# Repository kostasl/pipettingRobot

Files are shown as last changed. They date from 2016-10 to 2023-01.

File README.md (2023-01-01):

## Liquidhandler Robot 
@author: Konstantinos Lagogiannis 

This project provides part of the resources required to make an automated pipetting machine (robot)
that can be used in biology labs or just for fun.

The project describes the hardware  and assembly requirements  
along with the electronic and code components to build a gantry robot on which a 
standard pipeteman can be mounted. 
check out:https://hackaday.io/project/161546-pippeting-robot

The original idea is based on opentrons, ot.one however this design is heavily modified and simplified on the the controller side as it  does not require a connected PC to run. This also means it does not provide the all the functionality and flexibility of the OT.ONE software platform. It can be used as a simple platform to run repetitive procedures that can be coded on the controller or saved on a SD card. 

However, at this stage only the controller code is publicably available on this repository.
The code is part of an opensource project I wish to make on an affordable lab pipetting robot that can mount a standard lab pipette. 

A video of the prototype can be found here : https://www.youtube.com/watch?v=jlGT0nzT_E8

The provided version of the code operates the prototype  and can provide the basis for future development. However, I have yet to provide sufficient documantation for thise project , and thus thus this holds back release to the public domain as a complete open project which I can share.

*************************************

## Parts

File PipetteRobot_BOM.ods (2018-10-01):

Pipette Robot BOM
Category | Part Number | Part Name | Quantity | Description | Supplier | Price
Lasercut
 | 1001 | Baseplate | 1 | 6061 Aluminum, Anodized, 3mm
 | 1002 | Motor Mount Plate | 5 | Acrylic, 3mm
 | 1003 | Computer Mount Set | 1 set | Acrylic, 3mm
 | 1004 | Home Switch Mount Set | 1 set | Acrylic, 3mm
 | 1005 | Z Rail Spacer | 1 | Acrylic, 5mm
 | 1006 | Pipette Rail Mount | 1 | Acrylic, 5mm
 | 1007 | A Motor Mount Set | 1 set | Acrylic, 8mm
 | 1008 | Z Motor Mount | 1 | Acrylic, 8mm
 | 1009 | Z Motor Lock | 1 | Acrylic, 8mm
 | 1010 | Cable Rail Bracket | 2 | Acrylic, 8mm
 | 1011 | Baseplate Rails | 1 set | Acrylic, 3mm, 8mm
 |  | 8mm Acrylic Sheet
 |  | 5mm Acrylic Sheet
 |  | 3mm Acrylic Sheet
3D Print
 | 1100 | Belt Clip | 3 sets | PLA
 | 1101 | Pipette Holder | 1 | PLA
 | 1102 | Pipette Stopper | 1 | PLA
 | 1106 | Z Motor Mount | 1 | PLA
 | 1107 | Z Motor Lock | 1 | PLA
 | 1150 | Tip Clip | 1 | PLA
 | 1151 | Z Switch Block | 1 | PLA
 | 1152 | Pipette Rail Mount | 1 | PLA
Motors and Wheels
 | 1200 | Nema 17 Stepper Motor | 3 | Motor used for Y1, Y2, and X rails | Zapp | 42.78
 | 1201 | Nema 17 Stepper Motor - JK42HS40-1004YAL | 1 | Motor used for Z Axis, 300mm Captive Lead screw | Banggood | 20.44 | Zapp | 59.4
 | 1202 | Nema 17 Stepper Motor | 2 | Motor used for A pipette, 100mm Captive Lead screw | Zapp | 118.8
 | 1203 | Pulley | 3 | MX5-20 pulley for Y1, Y2, and X motors | Amazon | 7
 | 1204 | Wheels | 16 | Delrin V-Profile Wheel Kit | http://ooznest.co.uk/Solid-V-Wheel | 63.05
 | 1205 | Belt | 3 | MX5-belt – 600mm | Amazon | 0
 |  |  | 1 |  | http://robotseed.com/index.php?id_product=13&controller=product&id_lang=2 | 135.6
Electrical / Electronic
 | 1300 | Homeswitch | 4 | Micro switch used for homing feedback
 | 1301 | Homeswitch Cable | 2 | 3 pin, 2m long for Z and A home switch
 | 1302 | Homeswitch Cable | 2 | 3 pin, 1 m long for X and Y home switch
 | 1303 | Motor Cable | 4 | 4 pin, 2m long for Y, X, Z, and A motors
 | 1304 | Y-Split Cable | 1 | 4pin splits into two sections for Y1, and Y2 motor. 41Cm long
 | 1305 | Power Supply | 1 | 12V, 5.0A
 | 1306 | Power Button | 1
 | 1307 | Power Supply Cord | 1
 | 1308 | Drag Chain Cable Carrier 10 x 20mm | 2 |  | amazon sourcing map | 17.28
 | 1309 | Aluminum Board Case | 1 | 145mm x 85mm x 200mm
 |  | Arduino Duo Controller | 1 set | Runs Motor Loop/Reads Data from SD Card (To Be specified)
 |  | OLED Screen for Joystick | 1 set | Screen (To Be specified)
 |  | SD Card Reader | 1 set | (To Be specified)
 |  | Analog joystick | 1 | (To Be specified)
 |  | push buttons | 4 | (To Be specified)
Nuts and Bolts
 | 1400 | M8 Flathead Socket Cap Screw | 10 | 14mm
 | 1401 | M5 Buttonhead Socket Cap Screw | 4 | 35mm | 92
 | 1402 | M5 Buttonhead Socket Cap Screw | 19 | 14mm
 | 1403 | M5 Buttonhead Socket Cap Screw | 14 | 12mm
 | 1404 | M5 Buttonhead Socket Cap Screw | 40 | 10mm
 | 1405 | M5 Buttonhead Socket Cap Screw | 15 | 8mm
 | 1406 | M4 Flathead Socket Cap Screw | 2 | 8mm
 | 1407 | M4 Buttonhead Socket Cap Screw | 6 | 10mm
 | 1408 | M4 Buttonhead Socket Cap Screw | 1 | 10mm
 | 1409 | M3 Sockethead Cap Screw | 5 | 12mm
 | 1410 | M3 Buttonhead Socket Cap Screw | 8 | 16mm
 | 1411 | M3 Buttonhead Socket Cap Screw | 24 | 12mm
 | 1412 | M3 Buttonhead Socket Cap Screw | 30 | 8mm
 | 1413 | M5 T-Slide Nut | 34 | 15mm x 15mm x 6mm
 | 1414 | M5 T-Slide Nut | 33 | 10mm x 10mm x 5mm
 | 1415 | M5 Locknut | 6
 | 1416 | M5 Elastic Nut Ball Nut | 4 | 13.5mm x 8.5mm x 4.5mm
 | 1417 | M4 Square Nut | 8
 | 1418 | M4 T-Slide Nut | 4 | 15mm x 15mm x 6mm
 | 1419 | M3 T-Slide Nut | 2 | 10mm x 10mm x 5mm
 | 1420 | M3 washer | 8
 | 1421 | M3 nut | 24
 | 1422 | M3 insert | 16 | 5mm height, press fit
 | 1423 | M5 Standoff | 1 | 30mm length, Both sides female
 | 1424 | M3 Standoff | 12 | 45mm length, 1 side male 1 side female
 | 1425 | M3 Standoff | 4 | 60mm length, 1 side male 1 side female
 | 1426 | M3 Standoff | 4 | 6mm, 1 side male 1 side female
 | 1427 | L Bracket | 27 | 30mm x 30mm x 20mm
 | 1428 | L Bracket | 2 | 20mm x 20mm x 20mm
 | 1429 | 3-Side Bracket | 4 | 30mm x 30mm x 30mm
 | 1430 | Pin | 4 | 3mm Diameter, 8mm Height
 | 1431 | Precision Rod | 3 | 5mm Diameter, 100mm height | amazon sourcing map | 4.89
 | 1432 | Spacer | 3 | 5mm diameter, 8mm height
 |  | Mini V Precision Shim | 15 | 1mm thick | Ooznest | 4.2
 | 1433 | Phillips Self-Tap Screw | 4 | 16mm
 | 3842519318 | 20x20 Corner Bracket & Fixings (http://www.aluminium-profile.co.uk/cgi-bin/ss001001.cgi?PRODREF=3842519318&NOLOGIN=1) | 4 |  | http://www.aluminium-profile.co.uk/acatalog/Aluminium_Profile_Corner_Brackets.html#SID=15 | 12.6
Rails | 3842517146 | Domed Bracket Cap (http://www.aluminium-profile.co.uk/cgi-bin/ss001001.cgi?PRODREF=3842517146&NOLOGIN=1) | 4 |  | http://www.aluminium-profile.co.uk/acatalog/Aluminium_Profile_Corner_Brackets.html#SID=16 | 4.4
 | KJN523135 | M4 T Nut (10pk) (http://www.aluminium-profile.co.uk/cgi-bin/ss001001.cgi?PRODREF=KJN523135&NOLOGIN=1) | 40 |  | http://www.aluminium-profile.co.uk/acatalog/aluminium_Profile_T_Nuts.html#SID=8 | 12
 | KJN523140 | M4 Slide Block (10pk) | 10 |  | http://www.aluminium-profile.co.uk/acatalog/aluminium_Profile_T_Nuts.html#SID=9 | 10.2
 | KJN523511 | 20x20 L Bracket with Fixings | 32 |  | http://www.aluminium-profile.co.uk/acatalog/20x20-Bracket-with-Fixings-KJN523511.html#SID=26 | 41
 |  | M4x35mm A2 Stainless Steel Hex | 20 |  | amazon DBA | 2.57
 |  | M4x18mm CounterSank Flathead | 100 |  | amazon sourcing map | 7.96
 |  | M4x16mm A2 Stainless Steel Socket Allen Key Dome Head Bolt (https://www.amazon.co.uk/gp/product/B00A7BSOXW) | 100 |  | amazon | 6.6
 |  | M4x12mm ButtonHead Screws (20 Pack) | 20 |  | amazon | 1.45
 |  | M4x8mm Button Head 50pc | 50 |  | amazon | 2.9
 |  | M4 Square Nut A2 Stainless Steel (50 Pack). | 50 |  | amazon | 3.35
 |  | M4 Washer 4.3mm A2 Stainless Steel | 50 |  | amazon | 2.65
 |  | M3x12mm Countersunk Bolts | 20 |  | amazon | 2
 |  | M3x6mm Countersunk Bolts | 20 |  | amazon | 1.05
 |  | 100mm x 5mm HSS Ground Shaft Round Rod | 5 |  | amazon sourcing map | 4.89
 |  | Eccentric Spacer | 14 | Full Size wheel -Size 6mm | oozest | 28.01
 | 1500 | Frame – Base Rails | 4 | Aluminum Extrusion – J3030 – 20mm x 40mm x 500mm -BR Aluminium Profile 6mm slot | http://www.aluminium-profile.co.uk/ | 14
 | 1500 | Frame – Base Rails small | 5 | Aluminum Extrusion – KJN992888 – 20mm x 20mm x 500mm -BR Aluminium Profile 6mm slot | http://www.aluminium-profile.co.uk/ | 12.5
 | 1501 | Frame – Top Rails | 4 | Aluminum Extrusion – KJN992890 – 20mm x 20mm x 500mm BR Aluminium Profile 6mm slot | http://www.aluminium-profile.co.uk/ | 11.52
 | 1502 | Frame – Posts | 4 | Aluminum Extrusion – KJN992890 – 20mm x 20mm x 600mm | http://www.aluminium-profile.co.uk/acatalog/20x20-Aluminium-Profile--KJN992888.html | 13.44
 | 1503 | Frame – Cable Rail Support | 1 | Aluminum Extrusion – KJN992888 – 20mm x 20mm x 490mm |  | 2.46
 | 1504 | Frame – Cable Rail Support | 1 | Aluminum Extrusion – KJN992888 – 20mm x 20mm x 500mm |  | 2.5
 | 1505 | X and Y Linear Rail | 3 | Aluminum Extrusion – V-Profile – 20mm x 40mm x 500mm | http://ooznest.co.uk/ | 18
 | 1506 | Z Linear Rail | 1 | Aluminum Extrusion – V-Profile – 20mm x 40mm x 330mm |  | 7.2
 | 1507 | A Rail - Hold rail of Pippet Rail | 1 | Aluminum Extrusion – KJN992891 – 40mm x 20mm x 175mm |  | 1.55
 | 1508 | Pipette Rail | 1 | Aluminum Extrusion – KJN992888 – 20mm x 20mm x 125mm | http://www.aluminium-profile.co.uk/acatalog/20x40-Aluminium-Profile-KJN992891.html#SID=31 | 1
 |  |  |  |  | Total | 641.84

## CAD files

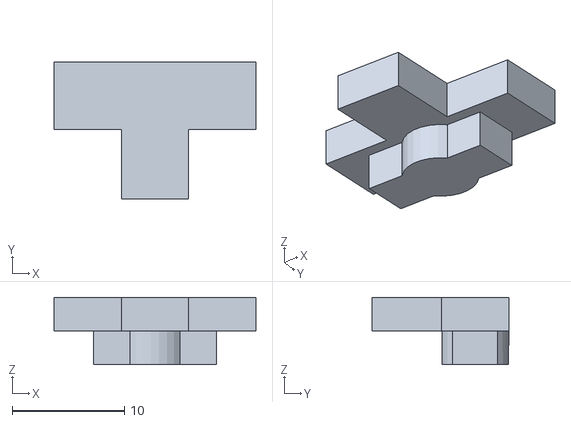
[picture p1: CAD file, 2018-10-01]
ToManufacture/Basis/1001_Guide05x4.stl
18.0 x 12.2 x 6.00

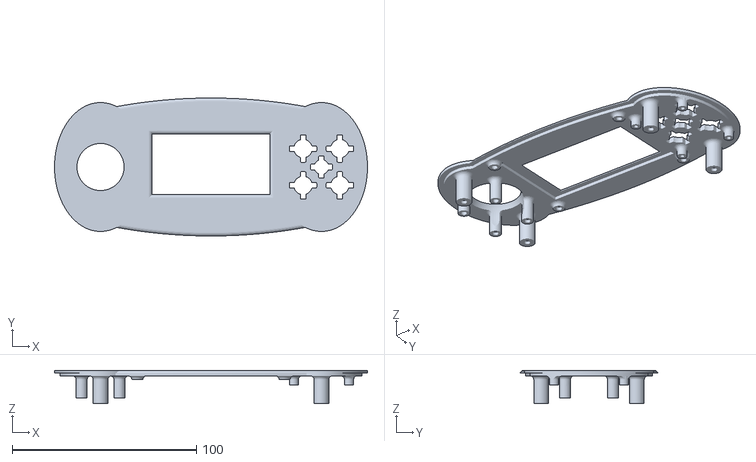
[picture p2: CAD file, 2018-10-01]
ToManufacture/JoystickCase_Front.stl
170.0 x 74.9 x 18.0

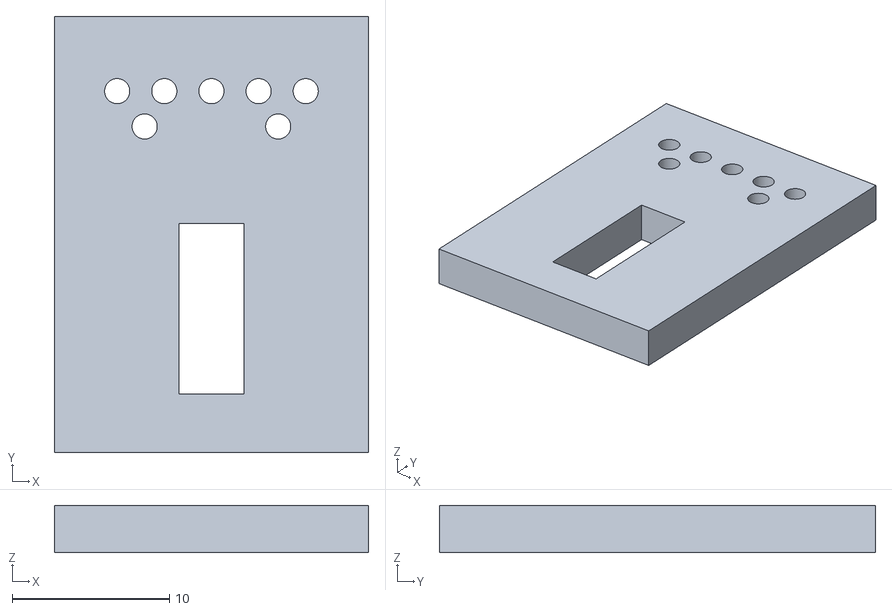
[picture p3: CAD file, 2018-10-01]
ToManufacture/1004_Home_Switch_Mount_Set.stl
20.0 x 27.8 x 3.00

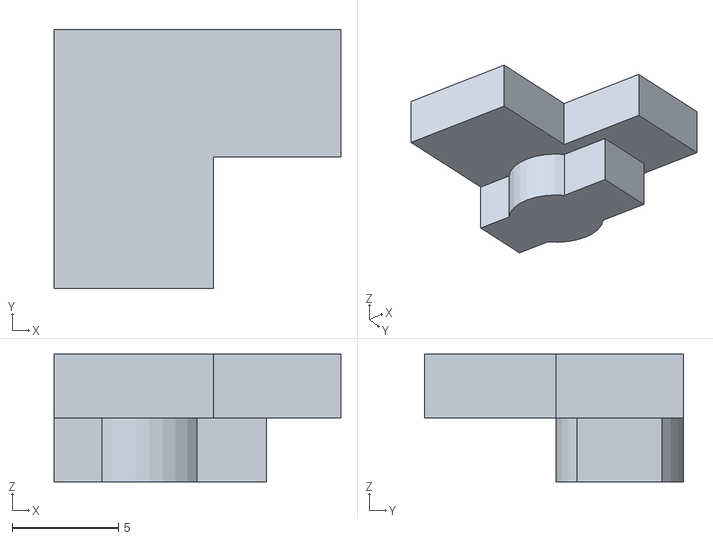
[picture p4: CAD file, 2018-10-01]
ToManufacture/Basis/1001_Guide03x2.stl
13.5 x 12.2 x 6.00

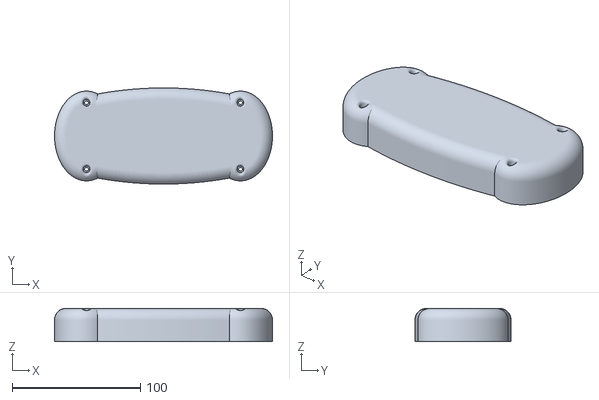
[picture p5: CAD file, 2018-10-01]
ToManufacture/JoystickCase_Back.stl
170.0 x 74.9 x 26.0

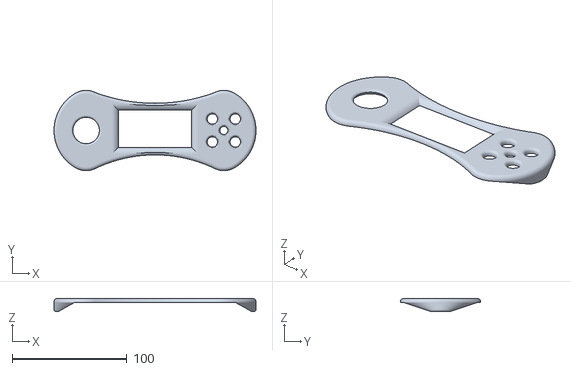
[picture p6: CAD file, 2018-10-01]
ToManufacture/JoystickCase_FrontRubber.stl
176.0 x 70.0 x 11.5

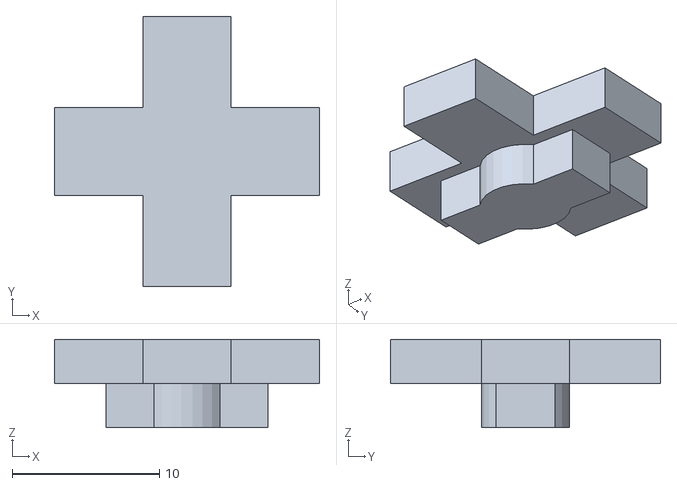
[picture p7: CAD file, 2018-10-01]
ToManufacture/Basis/1001_Guide06x4.stl
18.0 x 18.4 x 6.00

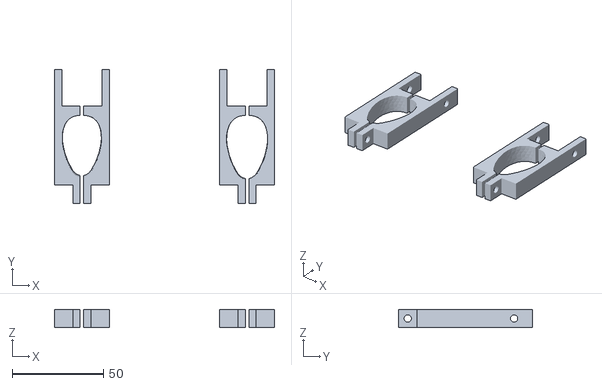
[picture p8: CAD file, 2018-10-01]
ToManufacture/Pipette_MountBoth.stl
120.5 x 73.2 x 10.00

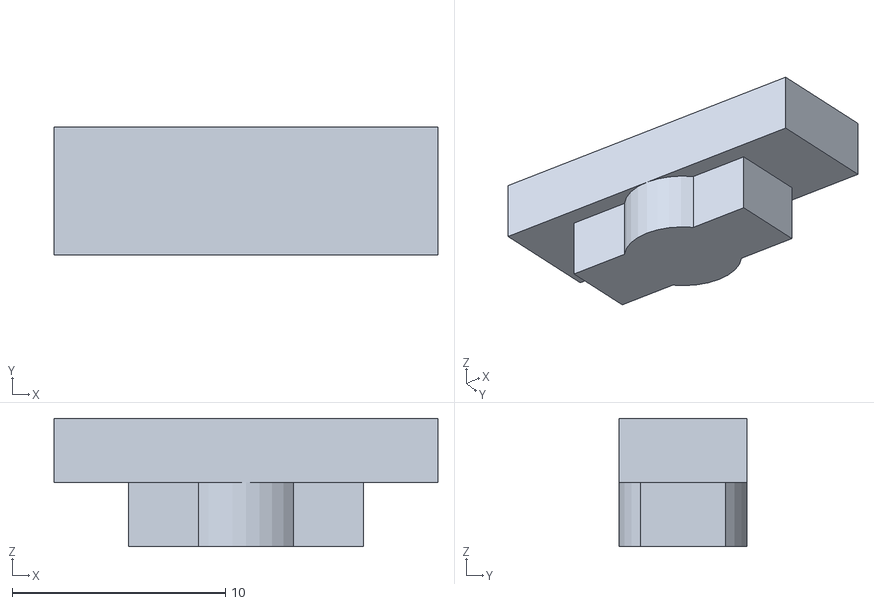
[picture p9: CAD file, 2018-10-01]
ToManufacture/Basis/1001_Guide01x2.stl
18.0 x 6.00 x 6.00

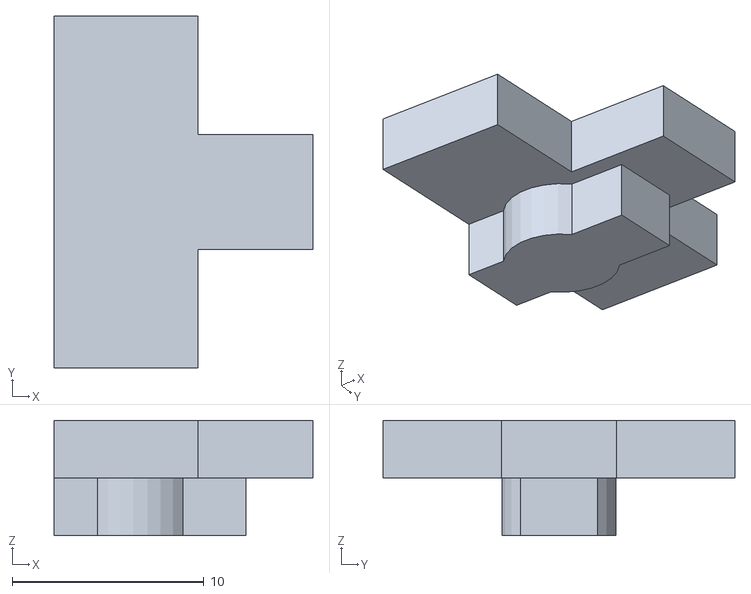
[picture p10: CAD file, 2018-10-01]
ToManufacture/Basis/1001_Guide04x4.stl
13.5 x 18.4 x 6.00

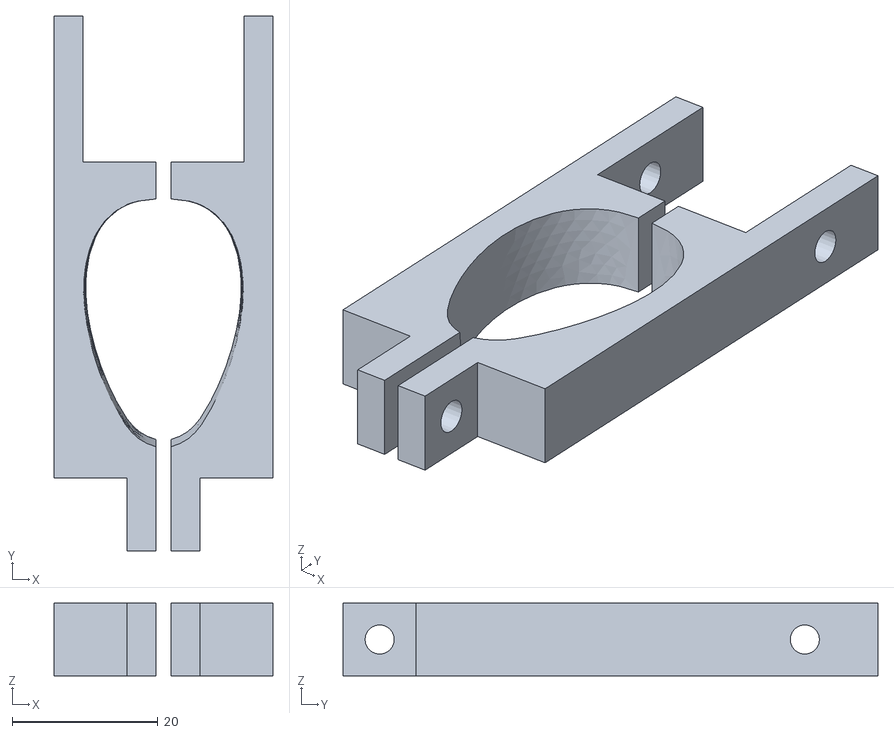
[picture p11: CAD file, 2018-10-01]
ToManufacture/Pipette_Mount1.stl
30.0 x 73.2 x 10.00

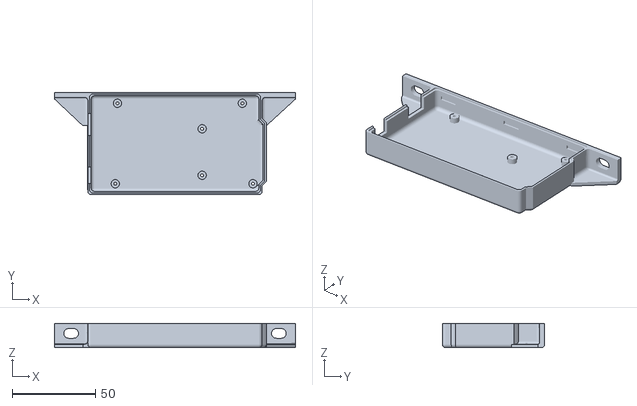
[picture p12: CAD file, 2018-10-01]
ToManufacture/arduino_mega_bottom.stl
144.5 x 61.3 x 14.5

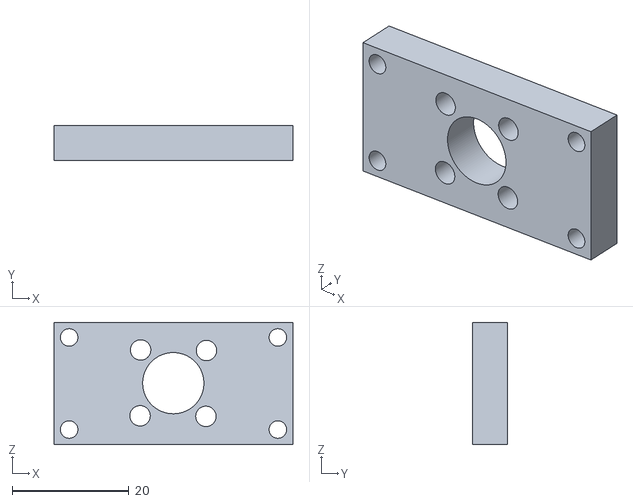
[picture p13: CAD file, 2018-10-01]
ToManufacture/1009_Z_Motor_Lock.stl
41.0 x 6.00 x 21.0

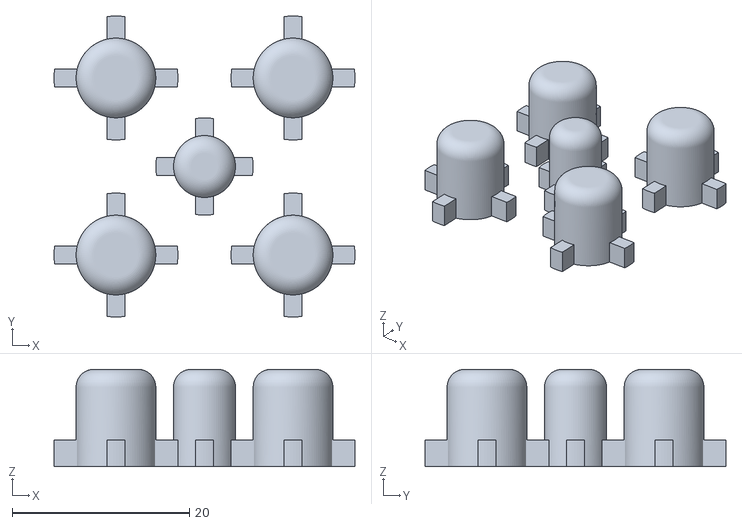
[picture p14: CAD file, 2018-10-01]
ToManufacture/Joystick_Buttons.stl
34.0 x 34.0 x 11.0

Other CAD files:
ToManufacture/Basis/1001_Guide07x2.stl
ToManufacture/Basis/1001_Guide02x2.stl
ToManufacture/1001_A_Baseplate.dwg
ToManufacture/1002_Z_Mount_Plate.stl
ToManufacture/PipettePress.stl
ToManufacture/Pipette_Mount2.stl
ToManufacture/Powersource_Mount.stl

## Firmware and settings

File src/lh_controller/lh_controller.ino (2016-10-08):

/*      Pipeting Robot Controller code -running on Arduino Mega 2560  ///////////////
// 
// Author: Kostas Lagogiannis costaslag@gmail.com 2016
// Synopsis:
    This code is to be used to run on the controller of the associated open hardware design pipetting machine.
    It drives the following peripherals:
    *Step. MotorDriver X,Step MotorDriver Y, Step MotorDriver  Z (Ballscrew), Step MotorDriver P (Non Captive ballscrew) -
    these are controller via 3 wire interface wired to the arduino board at pin number defined in the header file.
    We use a 3 wire interface to each MotorDriver (EN, DIR, STEP - HY-DIV268N-5A with active Low setup on pins)
    
    Using the AccelStepper Library V 1.51 that contains the Multistepper class too (not currently used)
    ///AccelStepper(uint8_t interface =AccelStepper::FULL4WIRE, uint8_t pin1 = 2, uint8_t pin2 = 3, uint8_t pin3 = 4, uint8_t pin4 = 5, bool enable = true);
    \param[in] is the Step input to the driver. Low to high transition means to step)
    \param[in] this is the Direction input the driver. High means forward
    \param[in] enable If this is true (the default), enableOutputs() will be called to enable the output pins at construction time.


    Display: 2.7inch OLED 128x64: Using Adafruit GFX and Adafruit1325 Driver 
    Font structures for newer Adafruit_GFX (1.1 and later).
    Example fonts are included in 'Fonts' directory.
    To use a font in your Arduino sketch, #include the corresponding .h
    file and pass address of GFXfont struct to setFont().  Pass NULL to
    revert to 'classic' fixed-space bitmap font.

    User interface: 5 buttons on right hand           + Joystick with Button On Left Hand
    1 2 1: Up Z Axis , 2: Up Pipette Axis              Button  (When Idle )starts programming mode (Prg Mode) Save position
     3  3: (When Idle Load & execute SD program) (Prog Mode) Stops Program Mode/Replays Saved Program       
    4 5 4: Down Z Axis, 5: Down Pipetter
// Note Any imported library is copied to the local sketchbook subfolder
//// Revision and Notes
// 26/5/16: -Bug : I changed something and the accelleration to Homing Has failed
// 4/6/16 : Changed pin wiring to use Digitalpins header, Moved definitions to dedicated header file  
// 10/6/16 Added Learning pos sequence via joystic - and replay- Note sometimes sequence run stops and needs to issue SST 4 again
// 12/06/12 Added Switch debouncing - Handling of 5 extra controller/joystick buttons for learning pos. 
   Problems To FIX:Jitter/drift on Y axis backwards,Z axis sometimes does not home completely thus zero position misplaced causes crash through tip holder!
  27/06/16 Added Support for SD Card
  03/07/16 There are issues with replay positionioning especially for P, Need to stop it from exceeding upper limit (where there is no switch - limit to steps 3500 / or add physical Sw)
  10/07/16 Made Program Saving/Loading from SD Card, with replay - But problems after 1st replay - loading again fails/readis from random mem
  11/07/16 Fixed bug above, was due to using free instead of delete/new combination for dyn memory alloc/dealloc
  23/07/16 Added Conservative error handling to avoid colission with Limit SW glitch //Was not enough-> Added manual dig pin read of SW in checkHoming to verify what the RDBButton Reads -
            This seems fix the glitch! prob bug in RDBLibrary!
            *Need to add HOMING before any Prog execution  - Also need to make SW clitches captured during replay
            
  02/10/16 Added homing before program loading, remove reset at homing
  04/10/16 Added 2 stage Homing (z 1st, then XYP), added menu scroll for loading and adding new program, changed to JoyButton for select
  05/10/16 Fixed Scrolling, But problem of freezing remains - I removed dynamic memory allocation and created a global buffer on the heap of MAX_POSITIONS - to Stop Freezing which was prob caused by mem fragmentation- 
           -Fixed Prog Relisting After running prog by rewinding Directory.
  06/10/16 Made Demo Program, fixed issue with execution freezing - It was due DistanceToGo innacuracy of hitting 0 target, making a catchment area solved the issue
  07/10/16 Making of Big Pipette Demo 
*/

#include <AccelStepper.h>
#include <MultiStepper.h>

//Headers for Screen Adafruit OLED  Monochrome OLEDs based on SSD1306 drivers 
#include <Wire.h>
#include <SPI.h>
#include <SD.h>

#include <Adafruit_GFX.h>
//#include <gfxfont.h>
#include <Adafruit_SSD1325.h>
//#include <Fonts/FreeMono7pt7b.h>
//#include <Fonts/FreeMono8pt7b.h>
#include <Fonts/FreeMono9pt7b.h>

//#include <FreeSerifItalic9pt7b.h>

//For Switch Debouncing
#include <RBD_Timer.h>
#include <RBD_Button.h>

#include "lh_controller.h"

#include <assert.h>
    
#if (SSD1325_LCDHEIGHT != 64)
#error(F("Height incorrect, please fix Adafruit_SSD1306.h!"));
#endif

//
File fileroot;


// Called Once on startup(after reset) for initialization //
void setup() {
  Serial.begin(9600);
  Serial.print(F("* Liquid Handler Controller Initializing \n"));
  inputString.reserve(100);
  
  //DISPLAY/
  // by default, we'll generate the high voltage from the 3.3v line internally! (neat!)
  //display.begin(SSD1306_SWITCHCAPVCC, 0x3C);  // initialize with the I2C addr 0x3D (for the 128x64)
  display.begin();
  delay(50);
  
  Serial.print(F("*Set Welcome Screen * \n"));
  dispWelcome();
  display.clearDisplay();
  display.display();
  Serial.print(F("*Done * \n"));

  
  // Configure each stepper
  stepperX.setEnablePin(PIN_MOTOR_X_EN);
  stepperX.setPinsInverted(true,true,true);
  stepperX.setCurrentPosition(0);  
  // Then give them to MultiStepper to manage
  //steppers.addStepper(stepperX);

  stepperY.setEnablePin(PIN_MOTOR_Y_EN);
  stepperY.setPinsInverted(true,true,true);
  stepperY.setCurrentPosition(0);
 	
  // Then give them to MultiStepper to manage
  //steppers.addStepper(stepperY);

  stepperZ.setEnablePin(PIN_MOTOR_Z_EN);
  stepperZ.setPinsInverted(true,true,true);
  stepperZ.setCurrentPosition(0);
  
  // Then give them to MultiStepper to manage
  //steppers.addStepper(stepperZ);

  stepperP.setEnablePin(PIN_MOTOR_P_EN);
  stepperP.setPinsInverted(true,true,true); //Not Inverting Direction - +ve are towards Home Switches
  stepperP.setCurrentPosition(0);
     
  // Then give them to MultiStepper to manage
  //steppers.addStepper(stepperP);


//CAn Use Debounce RDB Buttons Here TOo
 pinMode(PIN_SW_BT1,INPUT_PULLUP); //Joystic Sw Setup
 pinMode(PIN_SW_BT2,INPUT_PULLUP); //Joystic Sw Setup
 pinMode(PIN_SW_BT3,INPUT_PULLUP); //Joystic Sw Setup
 pinMode(PIN_SW_BT4,INPUT_PULLUP); //Joystic Sw Setup
 pinMode(PIN_SW_BT5,INPUT_PULLUP); //Joystic Sw Setup
 pinMode(PIN_SW_XL,INPUT_PULLUP);
 pinMode(PIN_SW_YF,INPUT_PULLUP);
 pinMode(PIN_SW_YB,INPUT_PULLUP);
 pinMode(PIN_SW_ZT,INPUT_PULLUP);
 pinMode(PIN_SW_PB,INPUT_PULLUP);
 
 pinMode(PIN_CS_SDCARD,OUTPUT); //Set To it must be left as an output or the SD library won't work.

//Set SW  Debounce To longer - Avoid Noisy Signals.
btn_PB_lim.setDebounceTimeout(BTN_DEBOUNCE_TIMEMS);
btn_ZT_lim.setDebounceTimeout(BTN_DEBOUNCE_TIMEMS);
btn_YB_lim.setDebounceTimeout(BTN_DEBOUNCE_TIMEMS);
btn_YF_lim.setDebounceTimeout(BTN_DEBOUNCE_TIMEMS);
btn_XR_lim.setDebounceTimeout(BTN_DEBOUNCE_TIMEMS);
btn_XL_lim.setDebounceTimeout(BTN_DEBOUNCE_TIMEMS);

  //Load Saved Positions

  //savedPositions[0] = (t_position)800,800,200,100};
  iposSaveIndex = 0; //pos to save next Pos;
  iposCurrentIndex=0;

///SD Card Init /cHIP Select is on 53 (which is also the SPI default)

  Serial.print(F("Initializing SD card..."));

  if (!SD.begin(53)) {
    Serial.println(F("initialization failed!"));
    return;
  }
  Serial.println(F("initialization done."));

  fileroot = SD.open("/");
  printDirectory(fileroot, 0);
  fileroot.close();

  
 // resetVars(); //IDLE Will Call Reset

  setMotorHomeSpeeds();//Set To Slow Homing Speeds
} //End Of Setup



void loop() {
  
  //Handle expiration/end of system state
  //State Expired
  if ((stateTimeOut < millis()) && stateTimeOut != 0)
  {
   stateTimeOut = 0;
   display.println(F("-TIMEOUT-"));
   display.display();
   delay(500);
   nextState = IDLE;
  }
  

//  if (nextState != systemState)
     //First Do Start Event Handling, because on these events some motor States may be set

if (nextState != systemState)
{
    handleStartStateEvents();
    
    dispState();
    if (systemState == TEST_RUN && nextState == MOVING){
      //Wait for It/Dont Slow Down Due to Display
      stepperX.run();  
      stepperY.run();    
      stepperZ.run();
      stepperZ.run();
    }
     else
      display.display();
}
else
    //Add State Events Events In Following function
    handleStopStateEvents();




//On Idle We show A menu On Every Cycle

  int limCnt = 0;
  //Check Limit Switch sensors and Stop Motion If needed Stop
  limCnt = checkHoming();

  //if (systemState != HOMING) //If LimitOut SW are pressed Speed is set to 0/ So dont do this when homing
  limCnt += checkOutOfRange();

  ////---CONSERVATIVE ERROR HANDLE - Raise error if SW is pressed while robot is moving/replay position
  //If Switched pressed while replay, then Hault Robot- Report Error
  if (limCnt > 0  && (systemState != HOMING && systemState != HOME && systemState != IDLE && systemState != JOYSTICK))
  {
  // nextState = POS_ERROR;
  }
  
  //Read Buttons And Limit Switches
  readJoystick();


///RUN STEP -- Need to Be Able to Move after Homed! So SW should be ignored
//Do multiple Calls Accelerates Movement, Jumping over the loop timing constraint
  
//Call Multiple Steps in loop to increase Speed (Each call executes 1 motor step maximum
for (int i=0; i<15;i++ )
{
    stepperX.run();  
    stepperY.run();    
    stepperZ.run();
    stepperZ.run();
    stepperZ.run();
    stepperP.run();
    stepperP.run();
    checkHoming();
}


////-------------------////

   //Handle Serial Commands
  // print the string when a newline arrives:
  if (stringComplete) {
    
    handleSerialCmd();
     // clear the string:
    inputString = "";
    stringComplete = false;
   }


  //update display Check if time to report to host
  if (stateReportInterval < millis())
  {//Report Every sec.
    stateReportInterval = millis()+500;

       
    if (stepperX.distanceToGo()==0 && stepperY.distanceToGo()==0 && stepperZ.distanceToGo()==0 && stepperP.distanceToGo()==0) //Display Updates disrupt the  Motion
    {
     if (!(systemState == TEST_RUN && nextState == MOVING)){
      {
        
      }
        //dispState();
        //display.display(); //Update display from Buffer
      }
    }
  }


}


void resetVars()
{
  
  //Initially savedPrograms[0] = 0;
  
  //Serial.print(F("\nProg Pointer: "));
  //Serial.println((unsigned int)savedPrograms);
  
  prog_init(&savedPrograms[0]); //Empties List
  

  //savedPositions[0] = (t_position)800,800,200,100};
  iposSaveIndex = 0; //pos to save next Pos;
  iposCurrentIndex=0;
}

//Called When INit or After Homing
void setMotorRunSpeeds()
{
  stepperX.setMaxSpeed(17000);
  stepperY.setMaxSpeed(17000);
  stepperZ.setMaxSpeed(15000);
  stepperP.setMaxSpeed(2500);

  stepperX.setAcceleration(18000); 
  stepperY.setAcceleration(18000);   
  stepperZ.setAcceleration(9500);   
  stepperP.setAcceleration(1500);

}

void setMotorHomeSpeeds()
{
  stepperX.setMaxSpeed(1100);
  stepperY.setMaxSpeed(1100);
  stepperZ.setMaxSpeed(10000);
  stepperP.setMaxSpeed(2500);

  stepperX.setAcceleration(2000); 
  stepperY.setAcceleration(2000);   
  stepperZ.setAcceleration(9500);   
  stepperP.setAcceleration(1500);

}


// handle diagnostic informations given by assertion and abort program execution:
void __assert(const char *__func, const char *__file, int __lineno, const char *__sexp) {
    // transmit diagnostic informations through serial link. 
    Serial.println(F("Assertion Failed"));
    Serial.println(__func);
    Serial.println(__file);
    Serial.println(__lineno, DEC);
    Serial.println(__sexp);
    Serial.flush();
    // abort program execution.
    abort();
}

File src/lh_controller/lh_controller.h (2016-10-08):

/* Header file
   Pipeting Robot Controller code -running on Arduino Mega 2560  ///////////////


*/
#define __ASSERT_USE_STDERR

#define TXT_TITLE          "-AutoPip-" // Machine Name


//  PIN DEFINITIONS //


#define PIN_MOTOR_P_EN    2 //Pipette drive
#define PIN_MOTOR_P_STEP  3
#define PIN_MOTOR_P_DIR   4

#define PIN_MOTOR_Z_EN    11
#define PIN_MOTOR_Z_STEP  12
#define PIN_MOTOR_Z_DIR   13

#define PIN_MOTOR_Y_DIR   24
#define PIN_MOTOR_Y_STEP  26
#define PIN_MOTOR_Y_EN    28

#define PIN_MOTOR_X_DIR   30
#define PIN_MOTOR_X_STEP  32
#define PIN_MOTOR_X_EN    34


#define PIN_AJR_X         0 //Joystick R
#define PIN_AJR_Y         1
#define PIN_SW_JR         36 //JoyStick R PushSwitch
#define PIN_SW_BT1        38 //JoyStick BTN 1 PushSwitch
#define PIN_SW_BT2        40 //JoyStick BTN 1 PushSwitch
#define PIN_SW_BT3        42 //JoyStick BTN 1 PushSwitch
#define PIN_SW_BT4        44 //JoyStick BTN 1 PushSwitch
#define PIN_SW_BT5        46 //JoyStick BTN 1 PushSwitch

#define PIN_CS_SDCARD     53 //Chipselect for SD Card 

//Limit Switches - X and Y axes have on both sides -Mounted On Header PINS
#define PIN_SW_YB          23
#define PIN_SW_YF          25
#define PIN_SW_XR          27
#define PIN_SW_XL          29
#define PIN_SW_ZT          31
#define PIN_SW_PB          33

#define LH_MIN_JOY_MOVE    20 //Minimum Joystick Reading Before Moving Motor
#define LIM_PIPETTE_UPTIX  -2800 //Upper Allowed position Of Pippete in #steps (stopping upper colission)

#define BTN_DEBOUNCE_TIMEMS 100 //DEbounce of LImit Switches in ms

#define MAX_NUMBER_OF_FILES 25 //Define Size of filename holding array

RBD::Button btn_YB_lim(PIN_SW_YB);
RBD::Button btn_YF_lim(PIN_SW_YF);
RBD::Button btn_XR_lim(PIN_SW_XR);
RBD::Button btn_XL_lim(PIN_SW_XL);
RBD::Button btn_PB_lim(PIN_SW_PB);
RBD::Button btn_ZT_lim(PIN_SW_ZT);

RBD::Button btn_JR_lim(PIN_SW_JR); //Joystic Button Press
bool flag_P_lim = false; //Flag holding state of Soft Limit Switch


// These are neede for both hardware & softare SPI /Modified lib to give SPI_CLOCK_DIV4 
#define OLED_RESET          49
#define OLED_DC             48
#define OLED_CS             47 //Cannot use Blue Cable on which MISO Port is on, when in SPI mode

//For Future SD Card Reader SPI Use 
///N/A The Green MISO Line Is unused -
//ChipSelect >?

#define MAX_POSITIONS 100 //Size Of Position Buffer
#define MAX_PROGS 1

// EG X-Y position bed driven by 2 steppers
// Alas its not possible to build an array of these with different pins for each :-(
// Up to 10 steppers can be handled as a group by MultiStepper

// Defines a target position to which the robot will move into - Coords defined as stepper positions
//Be carefu
struct list_position {
  uint8_t    seqID;//Id In Position Sequence
  int16_t     Ppos;
  uint16_t    Xpos;
  uint16_t    Ypos;
  uint16_t    Zpos;
  struct list_position  *epomPos; //Next Position   - Null Means  this Final Position
}; 

typedef struct list_position prog_position;

typedef struct {
  uint16_t ID;
  uint16_t posCount; //Number of positions
  uint8_t repsRemain; //Defines remaining Number of repetitions during a run
  uint8_t totalReps; //Total  Number of repetitions of a subroutine
  char progname[18]; //The program Name
  char timestamp[10]; //Last Mod Date
  list_position* protoPos;
  list_position* epiPos;
  list_position* telosPos;
  
} t_program;


//list_position savedPositions[MAX_POSITIONS];
t_program savedPrograms[MAX_PROGS]; //Array Of pointers to Saved Programs
prog_position gposbuffer[MAX_POSITIONS]; //Pointer To statically allocated Memory Buffer to save positions


int iposSaveIndex     = 0; // Index Of last position saved on this program  
int iposCurrentIndex  = 0; //Index Of currently running position of program


AccelStepper stepperX(AccelStepper::DRIVER,PIN_MOTOR_X_STEP,PIN_MOTOR_X_DIR); // Defaults to AccelStepper::FULL4WIRE (4 pins) on 2, 3, 4, 5
AccelStepper stepperY(AccelStepper::DRIVER,PIN_MOTOR_Y_STEP,PIN_MOTOR_Y_DIR); // Defaults to AccelStepper::FULL4WIRE (4 pins) on 2, 3, 4, 5
AccelStepper stepperZ(AccelStepper::DRIVER,PIN_MOTOR_Z_STEP,PIN_MOTOR_Z_DIR); // Defaults to AccelStepper::FULL4WIRE (4 pins) on 2, 3, 4, 5
AccelStepper stepperP(AccelStepper::DRIVER,PIN_MOTOR_P_STEP,PIN_MOTOR_P_DIR); // Defaults to AccelStepper::FULL4WIRE (4 pins) on 2, 3, 4, 5

//MultiStepper steppers; -Not Currently Used - Needs to be customized

///Screen Vars   
//Adafruit_SSD1306 display(OLED_RESET);
// this is for hardware SPI, fast! but fixed oubs
Adafruit_SSD1325 display(OLED_DC, OLED_RESET, OLED_CS);

///STATE Variables
enum ENUM_LH_STATE {IDLE=1, HOMING=2,HOMING_XY=20, HOME=3, TEST_RUN=4, MOVING=5, JOYSTICK=6, SAVE_POSITION=7, LOAD_PROGRAM=8, SAVE_PROGRAM=9, RESET=10, POS_ERROR =11 ,LAST_STATE=12};

ENUM_LH_STATE systemState = LAST_STATE;
ENUM_LH_STATE nextState = HOMING;

//Limit Switches Global Variables
int stateSW_XL = 1;
int stateSW_XR = 1;
int stateSW_YF = 1;
int stateSW_YB = 1;
int stateSW_ZT = 1;
int stateSW_PB = 1;
int stateSW_JR = 1; //Joystick
int stateSW_BT1 = 1; //Joystick
int stateSW_BT2 = 1; //Joystick
int stateSW_BT3 = 1; //Joystick
int stateSW_BT4 = 1; //Joystick
int stateSW_BT5 = 1; //Joystick


int posJRx     = 0; //Joystick Analog position X
int posJRy     = 0; //Joystick Analog position X

/// Serial COMMAND interface ///
boolean stringComplete             = false;  // whether the string is complete
String inputString                 = "";         // a string to hold incoming data
unsigned long stateTimeOut         = 0; //An Auxiliary var to set when a state expires and system returns to IDLE
unsigned long stateReportInterval  =  0; //Used to Time a frequent serial output to host. so port does not freeze

//File Loading Variables
String gstr_progfilenames[MAX_NUMBER_OF_FILES]; //Pointer to Array of String Filenames
int gi_filelistSelectedIndex  = 0; //For Listing Programs, start 
int gi_numberOfProgFiles      = 0; //For Listing Programs, start 
int gi_startindexFileList     = 0; //Used For Scrolling Down List indicates First Element
String selectedProgramFile;


 char buff[130]; //Generic Alloc Memory For Messages / Serial
 
// Function Prototypes
int checkHoming(); //Check homing conditions and set pos to 0 when reached
void handleStartStateEvents(); //Handles actions linked to moving to new state
void handleStopStateEvents(); //Checks conditions for when current state end and transits to next one
int handleSerialCmd();

void dispWelcome();
void resetVars();
void setMotorSpeeds();

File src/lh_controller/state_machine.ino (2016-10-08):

/*

State Machine code

Note to convert this to separate compiled file, add the .ccp file extension and then , #include "Arduino.h",
*/
///////////////
//Run from the main loop on every iteration to check and handle the conditions that may end a state
///////////
long distRemain = 0; //Used to Sum Readings From Distance To Go

void handleStopStateEvents()
{
   //State finished  
  switch (systemState)
    {
      case IDLE: //1
      //ENDS when New Command is issued
        //stepperZ.setMaxSpeed(1);
        //stepperY.setMaxSpeed(1);
        //stepperX.setMaxSpeed(1);
        //stepperP.setMaxSpeed(1);
         nextState = IDLE;

         if (btn_JR_lim.onPressed()){
           if (selectedProgramFile == gstr_progfilenames[0]){
              nextState = JOYSTICK;
           }else
           if (selectedProgramFile == gstr_progfilenames[1]){
              nextState = HOMING;
              prog_DispenseFoodToVialsPos(savedPrograms,6*12); //DISPENSE FOOD Program
           }
           else{ //Load the selected File 
               nextState = LOAD_PROGRAM;
           }
         }

         //Shift Selected File With Joystick Movement
         if (posJRy > LH_MIN_JOY_MOVE && (gi_filelistSelectedIndex > 0))
         {
            gi_filelistSelectedIndex--;
            dispState();
            display.display();

         }
         
         if ((posJRy < -LH_MIN_JOY_MOVE) && (gi_filelistSelectedIndex < (gi_numberOfProgFiles-1)))
         {
            gi_filelistSelectedIndex++;
            dispState();
            display.display();
         }


      break;

      case HOMING: //2 //Focuses on lifting the Z axis out of Vials
        //Check if a PUMP Move has been completed
        if (checkHoming() > 3)  //Homing is complete Anyway
        {
          nextState = HOME;
        }else{        
          if (abs(stepperZ.distanceToGo()) < 50) //Carry on With Stage 2 Homing 
          {
            nextState = HOMING_XY;
          }else
            nextState = HOMING;
        }

         //Interrupt Button/
         if (stateSW_BT3 == 1){ //Click So as to Replay saved POsitions
          nextState = IDLE;
         }

      break;
      
      case HOMING_XY:
        if (checkHoming() > 3)  //Homing is complete Anyway
        {
          nextState = HOME;
        }else
          nextState = HOMING_XY;

         //Interrupt Button/
         if (stateSW_BT3 == 1){ //Click So as to Replay saved POsitions
          nextState = IDLE;
         }

         //Interrupt Button/
         if (stateSW_BT3 == 1){ //Click So as to Replay saved POsitions
          nextState = IDLE;
         }
                     
      break;

      
      case HOME: //3 //Reached Home - Stay Here Unclick Switches
            //If  a program has been loaded / Run It
            if (savedPrograms[0].posCount > 1)
            {
                nextState = TEST_RUN;
            }else //if not then wait until state timesout to IDLE
             {
                nextState = HOME;
             }
      break;      

      
      case TEST_RUN:
 
          
          nextState = MOVING;
      break;

      case MOVING:
            nextState = MOVING;
         distRemain = abs(stepperZ.distanceToGo())+ abs(stepperP.distanceToGo());
         if (stepperX.distanceToGo() == 0 && stepperY.distanceToGo() == 0 && distRemain < 8)
         {
            //displState();
          //Do not Exceed Last saved Position - Check If Next Is Null
           if (savedPrograms[0].epiPos){              
              nextState = TEST_RUN; //Do it again
           }else{ /////////////Choose Next Sequence OR End Program //////////////////////
              prog_clearPoslist(savedPrograms); //prog->posCount = 0; Reset The pos Counter And Overwrite The  existing Positions
              Serial.println("Seq Ended. Check Reps remain.");
              if (savedPrograms[0].repsRemain){ //Check if Program Has  multiSteps repeating routines (Fill a vial sequence) , And Get the next one 
                  savedPrograms[0].repsRemain--;              
                  savedPrograms[0].epiPos = getNextFillVialPosSequence(savedPrograms,savedPrograms[0].totalReps - savedPrograms[0].repsRemain); 
                  savedPrograms[0].protoPos = savedPrograms[0].epiPos; //Set As start of Prog Sequence

                  nextState = TEST_RUN;
              }else{
                  sprintf(buff,("End Prog i: %d "), savedPrograms[0].telosPos->seqID);
                  Serial.println(buff);
                  //DOne the sequence  //Reset Program To Beginning
                  savedPrograms[0].posCount = 1; //Stop From Running Again
                  //- Go Back HOME after and reset to Unload Program    //resetVars();
                  nextState = HOMING;
               }
         }

            //Interrupt Button/
           if (stateSW_BT3 == 1){ //Click So as to Replay saved POsitions
            nextState = IDLE;
           }
         } //IF Reached Position
      break;
      
      case JOYSTICK:
 
        stepperY.setMaxSpeed(2*abs(posJRy));
        stepperX.setMaxSpeed(2*abs(posJRx));
        stepperZ.setMaxSpeed(2300);
        stepperP.setMaxSpeed(1500);
        stepperZ.setAcceleration(3500);   

        
        if (abs(posJRy) > LH_MIN_JOY_MOVE)
        {
         stepperY.move(posJRy);
        }
        else
          stepperY.move(0);
          
        if (abs(posJRx) > LH_MIN_JOY_MOVE)
           stepperX.move(posJRx);
         else
           stepperX.move(0);

        if (stateSW_BT1 == 1)
        {
           stepperZ.move(-1200); //Up Z Axis
//           display.setCursor(0,0);
//           display.println("Z Up");
//           display.display();
        }
         //else
           
        if (stateSW_BT4 == 1) //Down Z Axis
        {
           stepperZ.move(1200);

        }
         //else
           //stepperZ.move(0);

        if(stateSW_BT1==0 && stateSW_BT4 == 0)
           stepperZ.move(0);

        if (stateSW_BT2 == 1) //Up Pippete
           stepperP.move(-400);

        if (stateSW_BT5 == 1) //Down Pippete
           stepperP.move(400);

         if(stateSW_BT2==0 && stateSW_BT5 == 0)
           stepperP.move(0);

        if (btn_JR_lim.onPressed()){ //Click So Save New Position
            nextState = SAVE_POSITION;
         }

        if (stateSW_BT3 == 1){ //Click So as to save POsitions to file
            nextState = SAVE_PROGRAM;
         }

           
      break;

      case SAVE_POSITION:

        //Only Move Back to Joystick Once Button Has been released          
        if (btn_JR_lim.onReleased()) //Click So Save New Position
          nextState = JOYSTICK;
        else
          nextState = SAVE_POSITION;

      break;
      case SAVE_PROGRAM:
          nextState = HOMING;
      break;
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

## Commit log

2016-05-26 Added Screen Handling and Homing State machine
2016-05-26 Fixed Homing
2016-05-26 Fixed Homing with order of Event Handling
    [lh_controller.ino]
2016-05-26 Fixed Display Updating Switches
    [lh_controller.ino]
2016-05-26 Fixed Display Update & speed homing Issues When Updating State
    [lh_controller.ino]
2016-05-26 Changed Event Order Processing - Had to revert To blocking call for axes Move After Homing
    [lh_controller.ino]
2016-05-28 Fixed Motion Smoothneess and LImit Stops Are now directional
    [lh_controller.ino]
2016-05-28 Stopping On bothXY limits fixed - and locks movent only when pushing agains sw
    [lh_controller.ino]
2016-06-02 replace display with new vesion
    [lh_controller.ino]
2016-06-04 Changed File Org, added header, and changed pin definition so to fit Header
2016-06-10 Fixed Long Number display - Fixing Sequence Ending - Tested Sequence Learning and Exec Success
    [lh_controller.ino]
2016-06-12 Added Control of extra 5 Buttonsfrom the joystic. Central Btn (3 ) goes from joystick to Replay State - Works
2016-06-12 Added The debounce library to handle Limit Switches
2016-06-12 Fixing Issues State transitions oinReplay - Now Goes Home Once Finished- Issues of Z axis positions and Y axis Jitter remain
    [lh_controller.ino]
2016-06-19 Fixed Homing after Hiting Limit Switches Issue
    [lh_controller.h, lh_controller.ino, motion_checks.ino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]
2016-06-19 Added Longer Switch debounce - Print Saved Position on LCD
2016-07-09 Added SD card Saving - P stepper inversion was removed and Upper limit Set
2016-07-10 INcreased Debounce of Limit Sw to 150ms, fixed linked list of positions SD card loading bug
    [SD_storage.ino, lh_controller.h, motion_checks.ino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]
2016-07-11 INcreased Debounce of Limit Sw to 250, Fixed Loaded RUn Sequence to Run Till end - Tested Ok
    [SD_storage.ino, lh_controller.h, state_machine.ino]
2016-07-12 Fixed Reload Program Issues, Made prog init and prog pos list clear functions
    [lh_controller.h, lh_controller.ino, state_machine.ino]
2016-07-15 Added P lim flag switch so to trigger only once when hit, decreased P lim, Increased Deboundce Time
2016-07-23 Added 2nd SW limit Switch checking and conservative error handling (not activated yet)
    [comm_handlers.ino, lh_controller.h, lh_controller.ino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]
2016-07-23 Fixed SW glitches - Issues seems to be bug around Button onPressed- Still isPressed Events seem to occur though -but programs can now execute
    [lh_controller.ino, motion_checks.ino, state_machine.ino]
2016-10-03 Added menu, file selection, increased motor speeds
2016-10-04 Added 2 stage Homing (z 1st, then XYP), added menu scroll for loading and adding new program, changed to JoyButton for select
2016-10-04 Fixed 2 stage Z homing, Improved Up/Down Menu Scrolling, Increased Z speed via 4x stepping
    [lh_controller.h, lh_controller.ino, state_machine.ino]
2016-10-05 Fixed Menu selection and scrolling
    [state_machine.ino]
2016-10-05 Converted To Global Memory buffer/removed dynamic mem alloc avoid mem fragmentation issue. Fixed Prog Reloading Issue by rewinding directory
    [SD_storage.ino, lh_controller.h, lh_controller.ino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]
2016-10-06 Fixed Prog List Mem runover, Added program Auto Generating
    [SD_storage.ino, lh_controller.h, lh_controller.ino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]
2016-10-06 Fixed Issue with program freezing due to positions accuracy being unreachable
    [lh_controller.h, lh_controller.ino, motion_checks.ino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]
2016-10-06 Fixed Issue with program freezing due to positions accuracy being unreachable / now with abs position
    [state_machine.ino]
2016-10-07 Made Big Pipette Demo Script
2016-10-08 Removed the X-Y catchment area, added CEntre button interrupt function, removed verbose when programming Food Vial
2016-10-08 Added sequence loading of vial program. added motor loop for increased Speed
2016-10-08 Added Different Homing And Run Speeds
2016-10-08 fIXED sEQUENCE LOADING ISSUES
    [lh_controller.ino, programs.ino, state_machine.ino]
2016-10-08 Fixed Positions , And Ratio of Z to XY steps
    [lh_controller.ino, motion_checks.ino, programs.ino]
2018-10-01 Added STL files for custom designed parts
    [1001_A_Baseplate.dwg, 1001_Guide01x2.stl, 1001_Guide02x2.stl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]
2018-10-01 Provisional BOM -
    Part number matching needs checking
    [PipetteRobot_BOM.xlsx]
2018-10-01 provisional BOM Added
    [PipetteRobot_BOM.ods]
